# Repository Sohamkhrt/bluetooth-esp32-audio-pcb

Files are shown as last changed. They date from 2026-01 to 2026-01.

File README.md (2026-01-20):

# bluetooth-esp32-audio-pcb
A custom Bluetooth Audio PCB for motorcycle helmets, powered by ESP32 and PCM5102A with integrated LiPo BMS and power management
raytracingpcbaudio
raytracingpcbaudio2



Project Highlights

Core Logic: ESP32-WROOM-32 for Bluetooth A2DP audio streaming.

Audio: High-fidelity I2S interface using the PCM5102A DAC (32-bit/384kHz capable).

Power Management: Integrated TP4056 LiPo charger with DW01A protection circuitry (Over-charge/Over-discharge/Short-circuit protection).

Regulation: Low-dropout (LDO) 3.3V regulation (AP2112K) with stable capacitor banking for RF noise suppression.

Technical Challenges Solved

MOSFET Matching: Resolved a critical pinout mismatch between standard TSSOP-8 and SOT-23-6 dual N-channel MOSFETs for battery protection.

Signal Integrity: Implemented dedicated ground planes (copper pours) on both layers with stitching vias to minimize EMI and ground loops for clear audio.

Space Constraint: Designed within a tight 50mm x 50mm form factor to fit inside a helmet cheek pad.

EDA Tool Used: KiCad 9.0

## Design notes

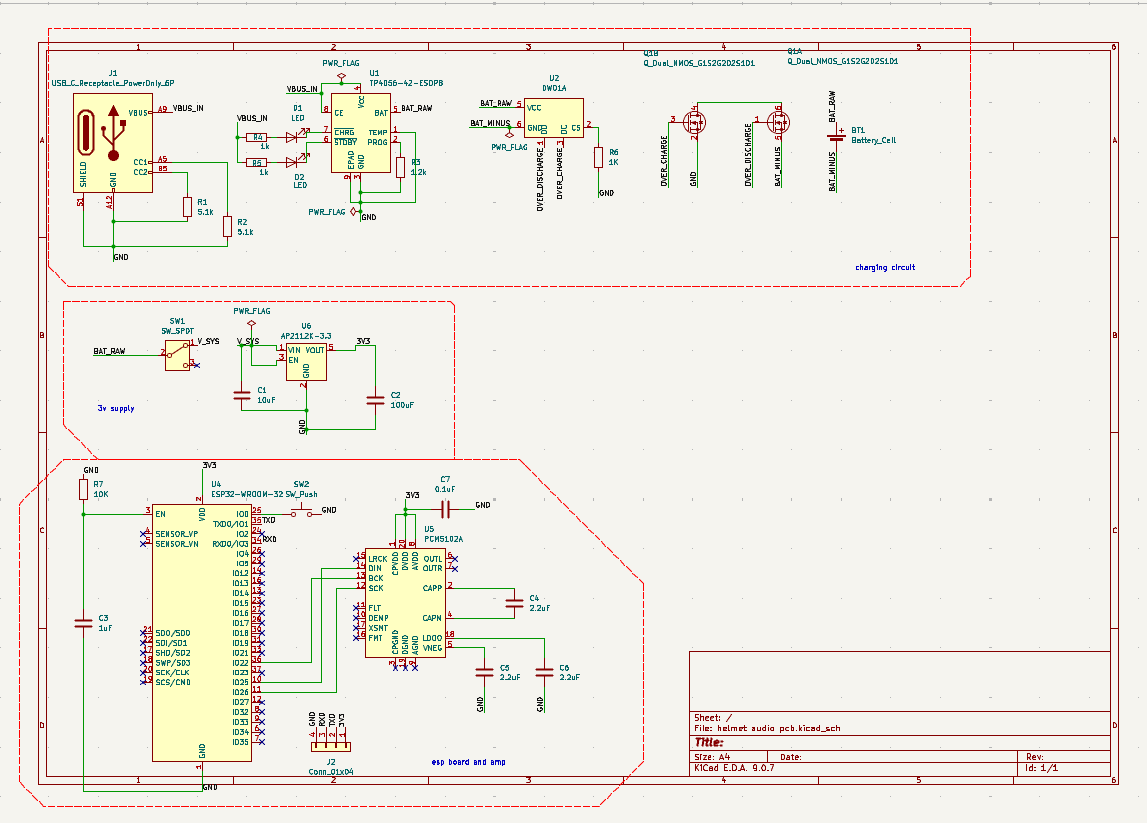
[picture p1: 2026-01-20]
schematics/Screenshot 2026-01-20 182503.png

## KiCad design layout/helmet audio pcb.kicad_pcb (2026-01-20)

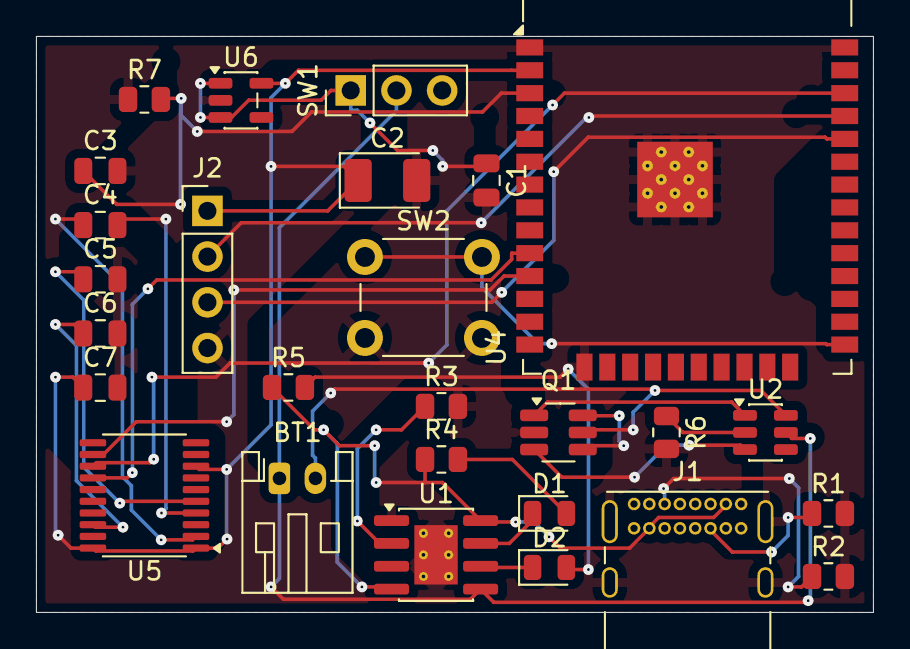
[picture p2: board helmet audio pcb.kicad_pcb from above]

Board: 2 copper layers, 46.5 x 32.0 mm, 27 parts (0 on the bottom side), 28 nets.

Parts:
BT1: Battery_Cell; JST_PH_S2B-PH-K_1x02_P2.00mm_Horizontal
C1: 10uF; C_0805_2012Metric
C2: 100uF; CP_EIA-3528-21_Kemet-B_HandSolder
C3: 1uF; C_0805_2012Metric
C4, C5, C6: 2.2uF; C_0805_2012Metric
C7: 0.1uF; C_0805_2012Metric
D1, D2: LED; LED_0805_2012Metric
J1: USB_C_Receptacle_PowerOnly_6P; USB_C_Receptacle_GCT_USB4085
J2: Conn_01x04; PinHeader_1x04_P2.54mm_Vertical
Q1: Q_Dual_NMOS_G1S2G2D2S1D1; SOT-23-6_Handsoldering
R1, R2: 5.1k; R_0805_2012Metric
R3: 1.2k; R_0805_2012Metric
R4, R5: 1k; R_0805_2012Metric
R6: 1K; R_0805_2012Metric
R7: 10K; R_0805_2012Metric
SW1: SW_SPDT; PinHeader_1x03_P2.54mm_Vertical
SW2: SW_Push; SW_PUSH_6mm
U1: TP4056-42-ESOP8; SOIC-8-1EP_3.9x4.9mm_P1.27mm_EP2.41x3.3mm_ThermalVias
U2: DW01A; SOT-23-6
U4: ESP32-WROOM-32
U5: PCM5102A; TSSOP-20_4.4x6.5mm_P0.65mm
U6: AP2112K-3.3; SOT-23-5

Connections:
/3V3: C2.1, C7.1, J2.1, U4.2 (VDD), U5.1 (CPVDD), U5.8 (AVDD), U5.20 (DVDD), U6.5 (VOUT)
/BAT_MINUS: BT1.2 (-), Q1.5 (S), U2.6 (GND)
/BAT_RAW: BT1.1 (+), SW1.2 (B), U1.5 (BAT), U2.5 (VCC)
/GND: C1.2, C2.2, C3.2, C5.2, C6.2, C7.2, J1.A12 (GND), J1.B12 (GND), J1.S1 (SHIELD), J2.4, Q1.2 (S), R1.2, R2.2, R3.2, R6.2, R7.1, SW2.2, U1.1 (TEMP), U1.3 (GND), U1.9 (EPAD), U4.1 (GND), U4.15 (GND), U4.38 (GND), U4.39 (GND), U6.2 (GND)
/OVER_CHARGE: Q1.3 (G), U2.3 (OC)
/OVER_DISCHARGE: Q1.1 (G), U2.1 (OD)
/RXD: J2.3, U4.34 (RXD0/IO3)
/TXD: J2.2, U4.35 (TXD0/IO1)
/VBUS_IN: J1.A9 (VBUS), J1.B9 (VBUS), R4.1, R5.1, U1.4 (V_{CC}), U1.8 (CE)
/V_SYS: C1.1, SW1.1 (A), U6.1 (VIN), U6.3 (EN)
unnamed: D1.2 (A), R4.2
unnamed: D1.1 (K), U1.7 (~CHRG)
unnamed: D2.2 (A), R5.2
unnamed: D2.1 (K), U1.6 (~STDBY)
unnamed: J1.A5 (CC1), R2.1
unnamed: J1.B5 (CC2), R1.1
unnamed: Q1.4 (D), Q1.6 (D)
unnamed: R3.1, U1.2 (PROG)
unnamed: R6.1, U2.2 (CS)
unnamed: C3.1, R7.2, U4.3 (EN)
unnamed: SW2.1, U4.25 (IO0)
unnamed: U4.36 (IO22), U5.13 (BCK)
unnamed: U4.10 (IO25), U5.14 (DIN)
unnamed: U4.11 (IO26), U5.12 (SCK)
unnamed: C4.2, U5.4 (CAPM)
unnamed: C4.1, U5.2 (CAPP)
unnamed: C6.1, U5.18 (LDOO)
unnamed: C5.1, U5.5 (VNEG)

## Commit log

2026-01-20 Create schematics
2026-01-20 added schematic files
